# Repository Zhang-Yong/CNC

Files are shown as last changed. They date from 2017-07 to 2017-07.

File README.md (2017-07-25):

# CNC
  My CNC project in 2013, this project makes myself familiar with mechnical design and installation. All the parts are built and assemblied in Solidworks before order on the net. I bought a bench drill to assemble every raw material. Below are drawings before and after build. After build it up, the CNC can move according to input x, y, Z axis.

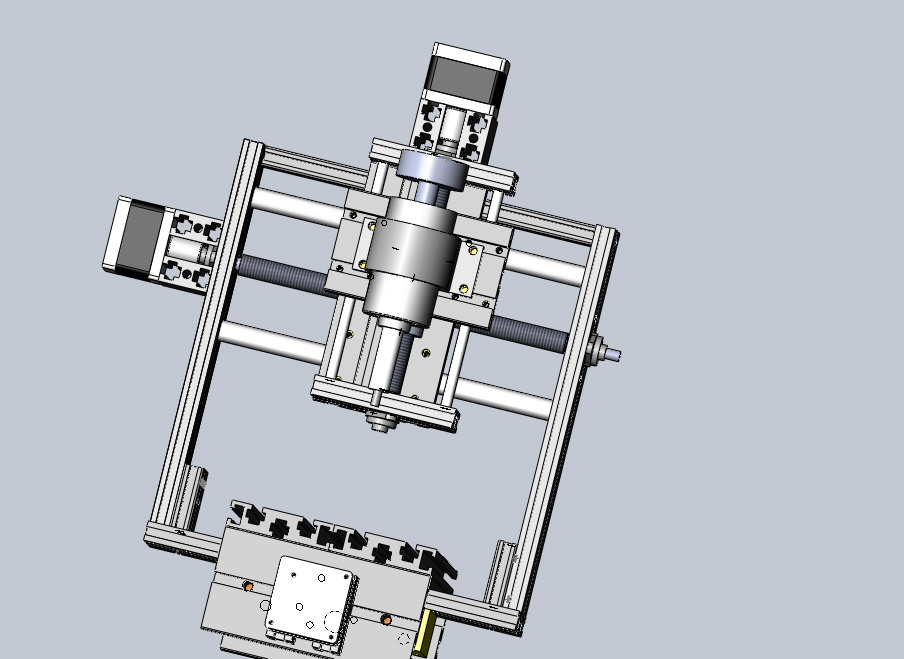
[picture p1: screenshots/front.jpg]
Front view


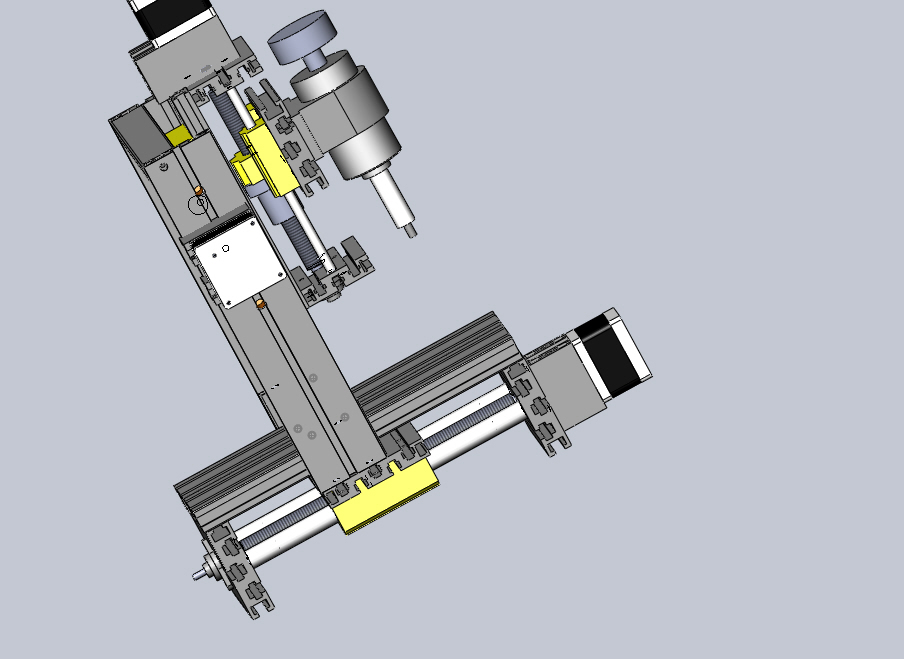
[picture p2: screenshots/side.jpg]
side view


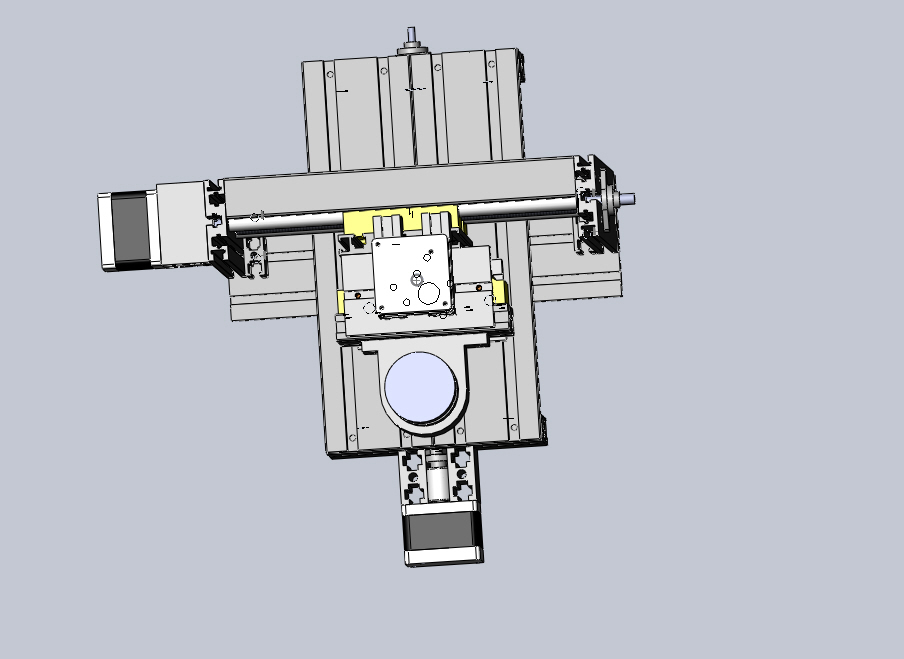
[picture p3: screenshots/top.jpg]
top view


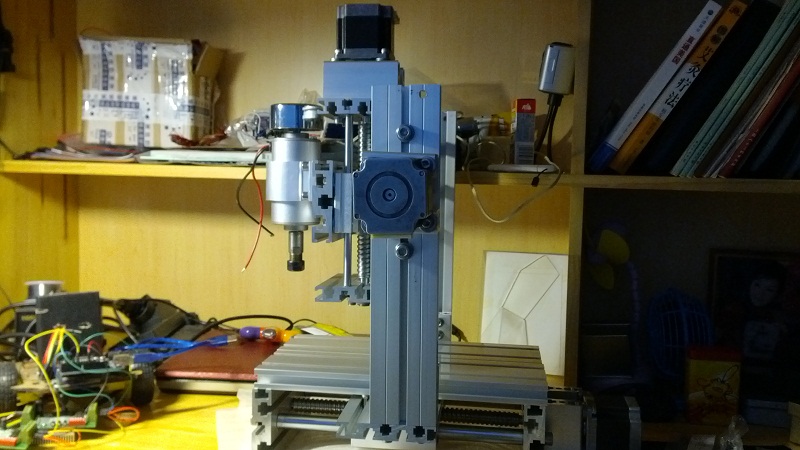
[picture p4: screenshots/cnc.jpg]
Real picture


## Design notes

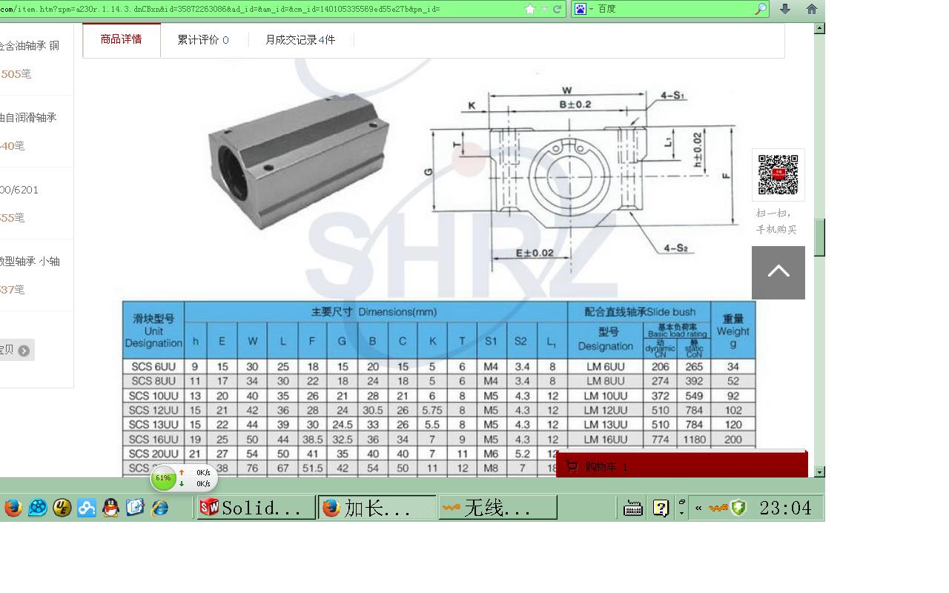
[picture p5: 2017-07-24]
my_CNC_Solidworks_File/┴у╝■═╝╞м/scs8LUU.JPG

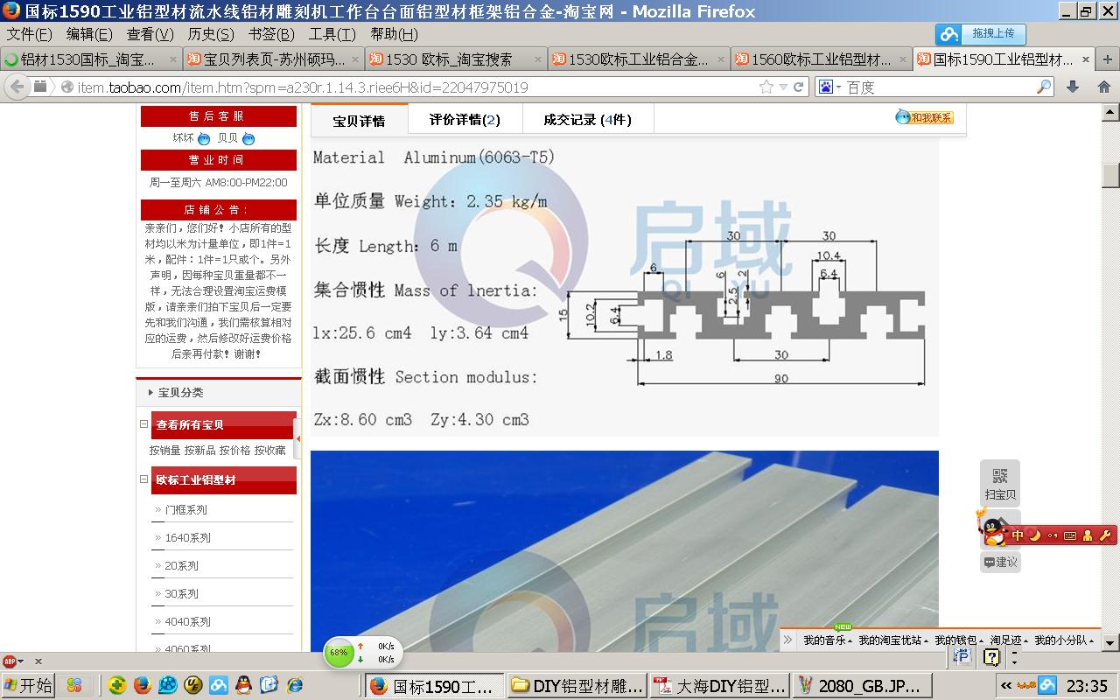
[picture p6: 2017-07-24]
my_CNC_Solidworks_File/┴у╝■═╝╞м/1590_GB.JPG

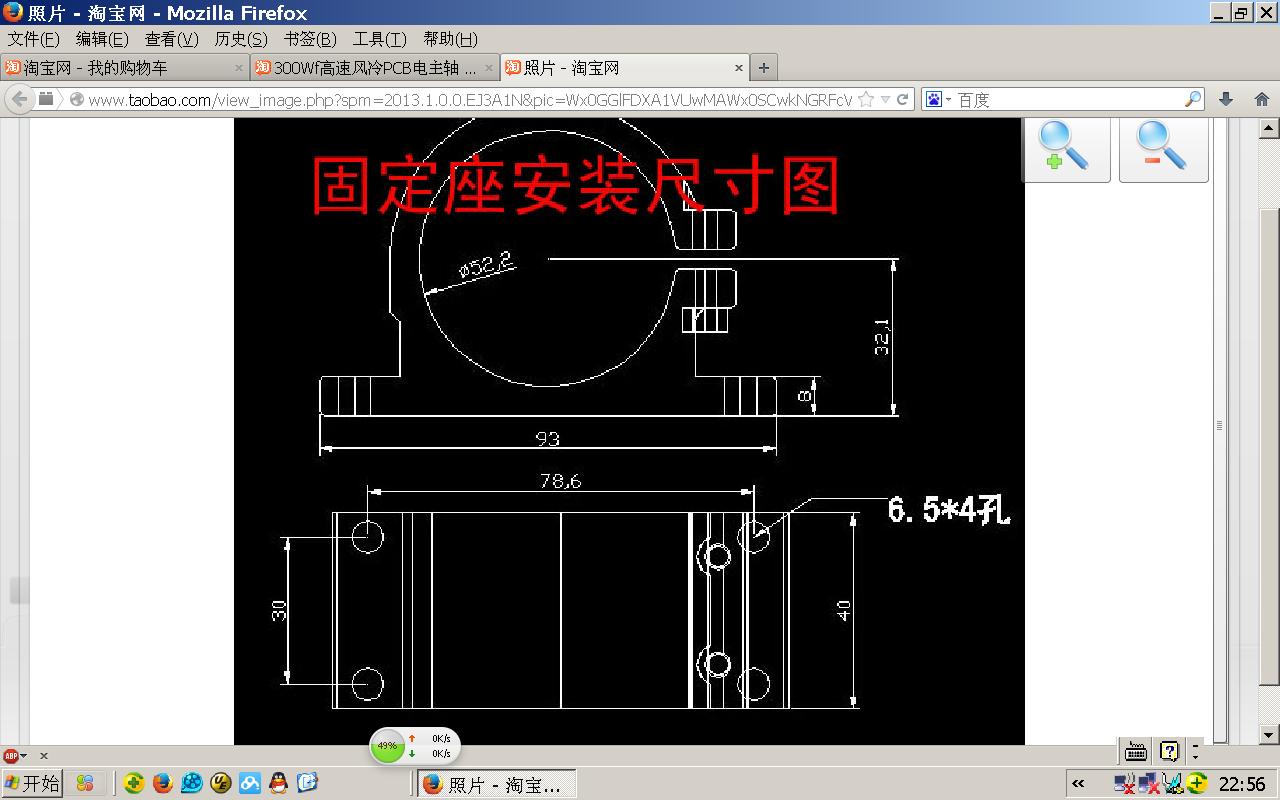
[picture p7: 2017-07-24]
my_CNC_Solidworks_File/┴у╝■═╝╞м/╓ў╓с╣╠╢и╫∙.JPG

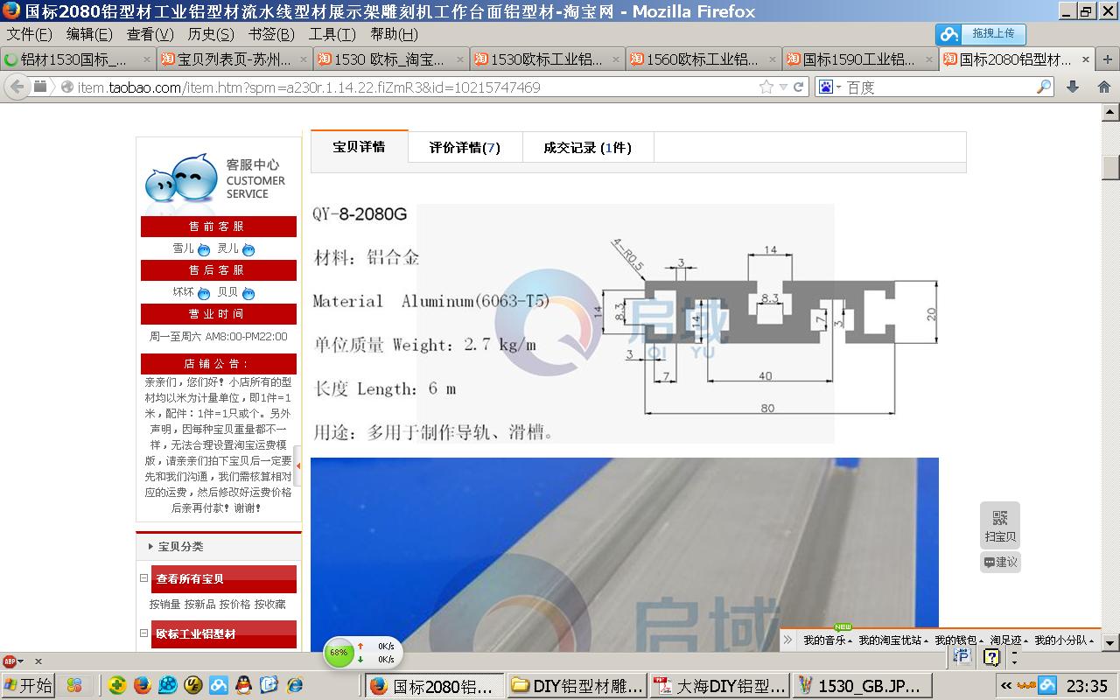
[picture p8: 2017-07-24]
my_CNC_Solidworks_File/┴у╝■═╝╞м/2080_GB.JPG

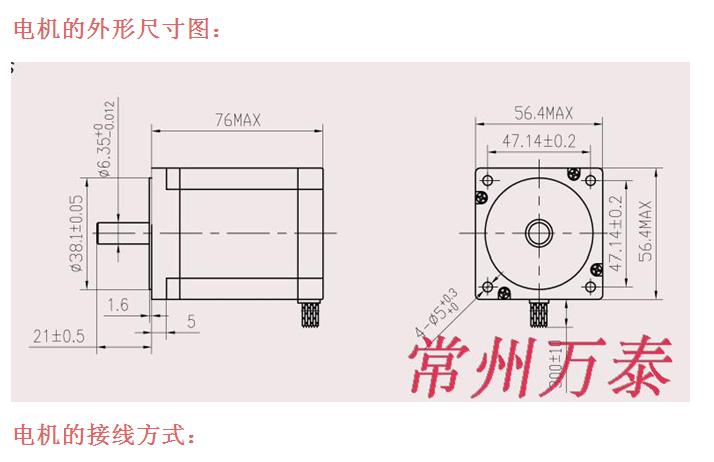
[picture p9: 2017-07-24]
my_CNC_Solidworks_File/┴у╝■═╝╞м/57▓╝╜°.jpg

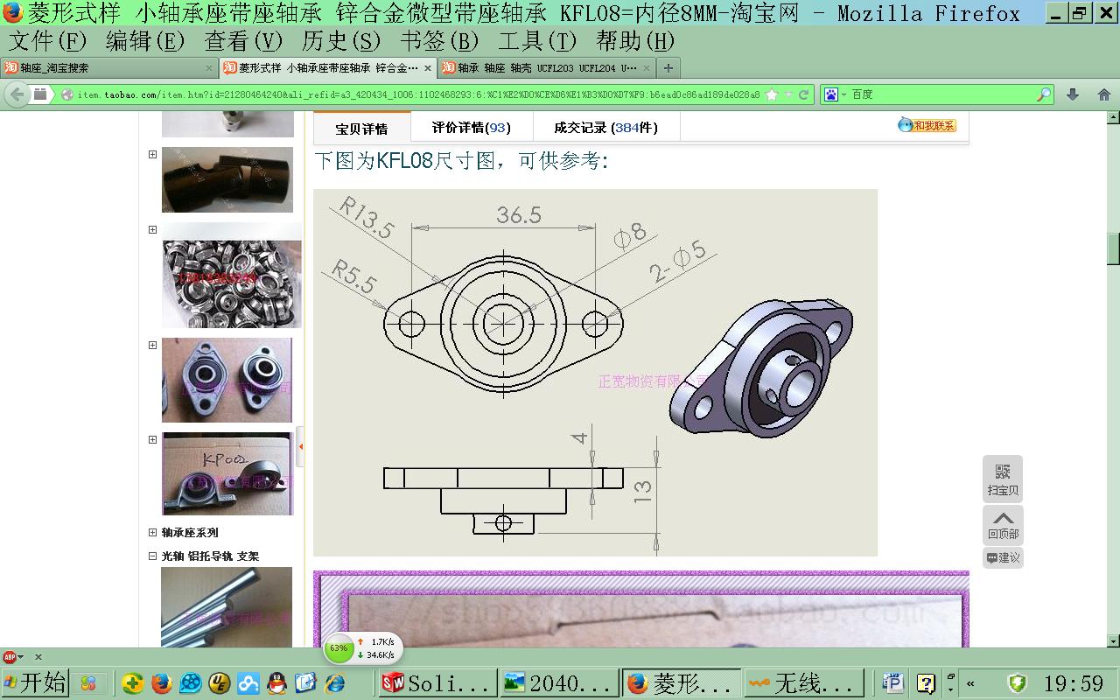
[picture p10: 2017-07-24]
my_CNC_Solidworks_File/┴у╝■═╝╞м/KFL08_╓с╫∙.JPG

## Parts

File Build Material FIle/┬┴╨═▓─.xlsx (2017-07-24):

 | 型号 | 标准 | 长度 | 数量 | 用途
铝型材 | 2080 | 国标 | 290 mm | 2 | 台面板
铝型材 | 2080 | 国标 | 160 mm | 2 | Y 轴前后板
铝型材 | 2080 | 国标 | 128 mm | 1 | Z 轴移动板
铝型材 | 1590 | 国标 | 290 mm | 1 | Y 轴移动板
铝型材 | 1590 | 国标 | 200 mm | 1 | X 轴移动板
铝型材 | 1560 | 国标 | 300 mm | 2 | X 轴左右板
铝型材 | 1560 | 国标 | 110 mm | 2 | Z 轴上下板
铝型材 | 2040A | 国标 | 75 mm | 2 | Z 轴电机固定板
铝型材 | 2040A | 国标 | 60 mm | 4 | XY 轴电机固定板
铝型材 | 1530 | 国标 | 260 mm | 1 | X 轴上连接板
铝型材 | 1530 | 国标 | 50 mm | 4 | XY 轴连接板
切割要求：
雕刻机用铝型材， 切割要精确， 断面要平整，没有毛刺。

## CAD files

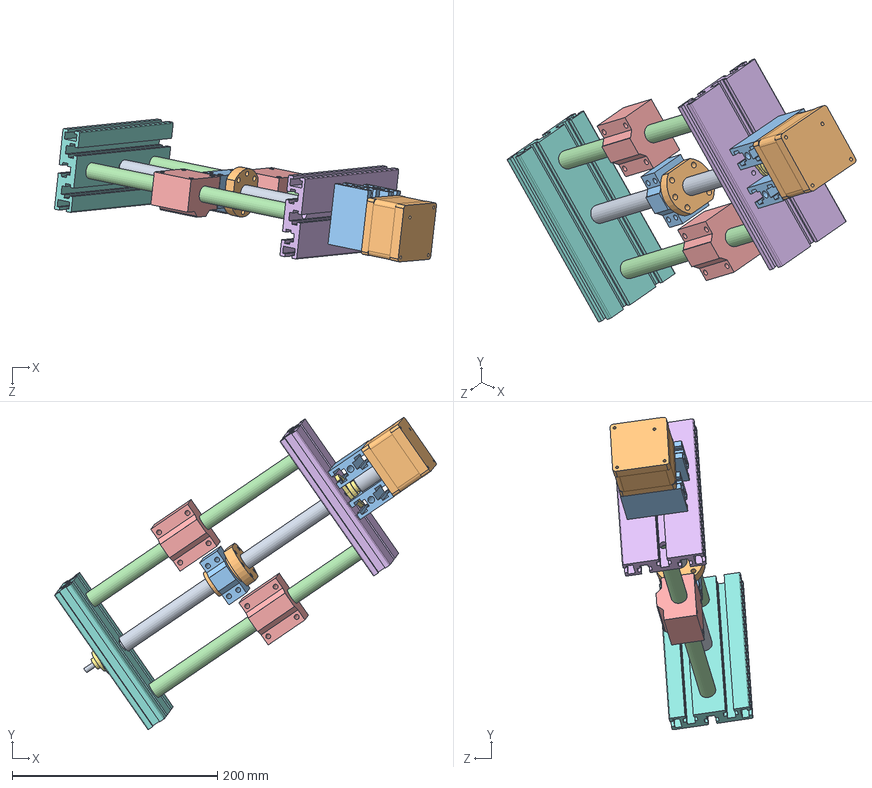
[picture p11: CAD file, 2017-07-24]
my_CNC_Solidworks_File/╫░┼ф╠х/╣Ў╓щ╦┐╕╦_Y.SLDASM
372.6 x 304.8 x 139.3 mm
滚珠丝杆_Y轴_T1605_new
滚珠丝杆1605螺母
SCS16UU_Half
光轴16x250mm_Y轴_new x 2
SCS16UU x 2
2080_160_Y_Back_电机
KFL08_轴座 x 2
2080_160_Y_Front_手轮
联轴器6_35x6_35
57步进电机轴
2040_GB_XY_60 x 2

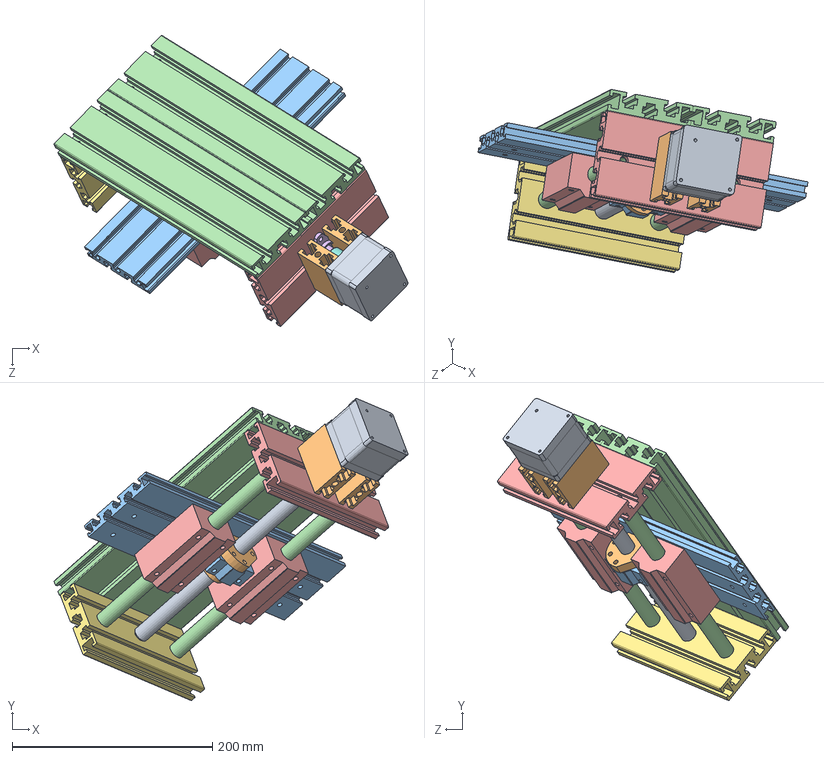
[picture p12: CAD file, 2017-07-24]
my_CNC_Solidworks_File/╫░┼ф╠х/Y_╓с_╠и├ц.SLDASM
353.5 x 301.8 x 291.0 mm
滚珠丝杆_Y轴_T1605_new
滚珠丝杆1605螺母
SCS16UU_Half
光轴16x250mm_Y轴_new x 2
2080_160_Y_Back_电机
KFL08_轴座 x 2
2080_160_Y_Front_手轮
联轴器6_35x6_35
57步进电机轴
2040_GB_XY_60 x 2
1590_290_Y
2080_Table_290_new x 2
SCS16LUU x 2

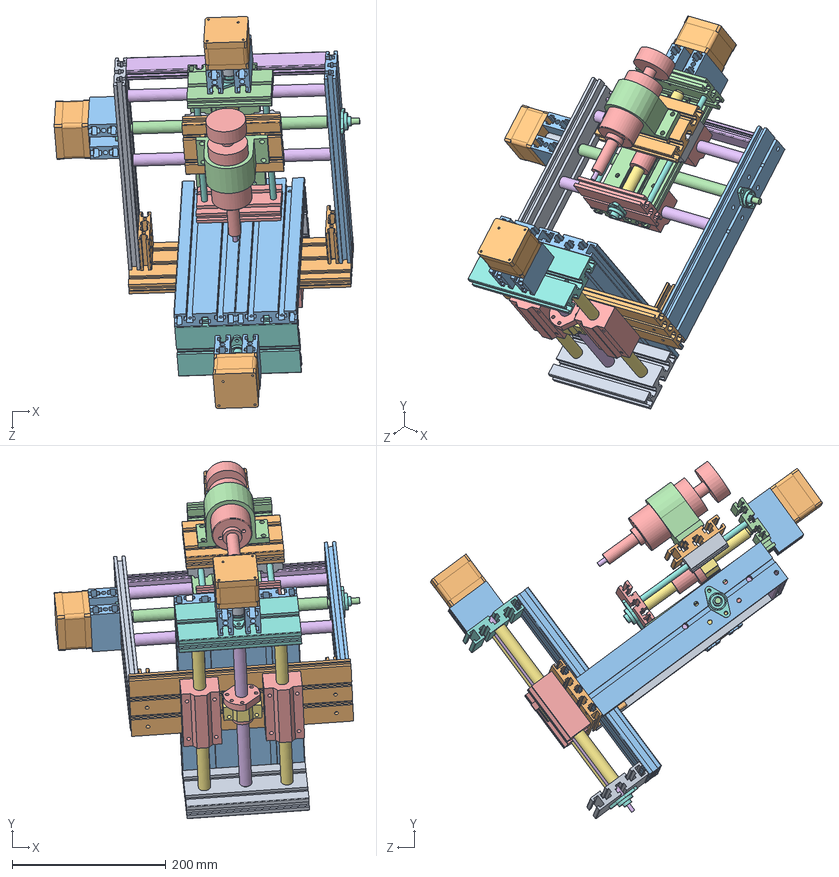
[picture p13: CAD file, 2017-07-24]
my_CNC_Solidworks_File/╫░┼ф╠х/╫▄╫░.SLDASM
398.0 x 465.4 x 510.4 mm
1560_300_X x 2
1530_50_XY x 4
1560_300_X_Right
滚珠丝杆_X轴_T1605
滚珠丝杆1605螺母 x 3
光轴16x250mm_X轴 x 2
SCS16UU_Half x 3
KFL08_轴座 x 6
联轴器6_35x6_35 x 3
57步进电机轴 x 3
2040_GB_XY_60 x 4
1590_200_X
SCS16LUU x 4
1530_260_X
滚珠丝杆_Z轴_T1605
光轴8x170mm_Z轴 x 2
SCS8LUU x 2
2080_128_Z
2040_GB_Z_75 x 2
1560_110_Z
1560_110_Z_下板
滚珠丝杆_Y轴_T1605_new
光轴16x250mm_Y轴_new x 2
2080_160_Y_Back_电机
2080_160_Y_Front_手轮
1590_290_Y
2080_Table_290_new x 2
主轴电机座
主轴电机
雕刻刀

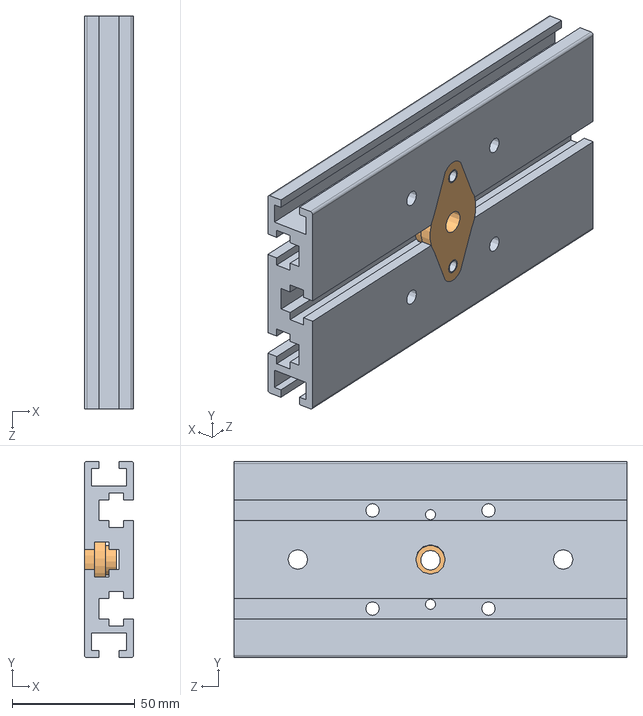
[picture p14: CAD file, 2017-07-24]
my_CNC_Solidworks_File/╫░┼ф╠х/╫░┼ф╠х2.SLDASM
20.0 x 80.0 x 160.0 mm
2080_160_Y_Back_电机
KFL08_轴座

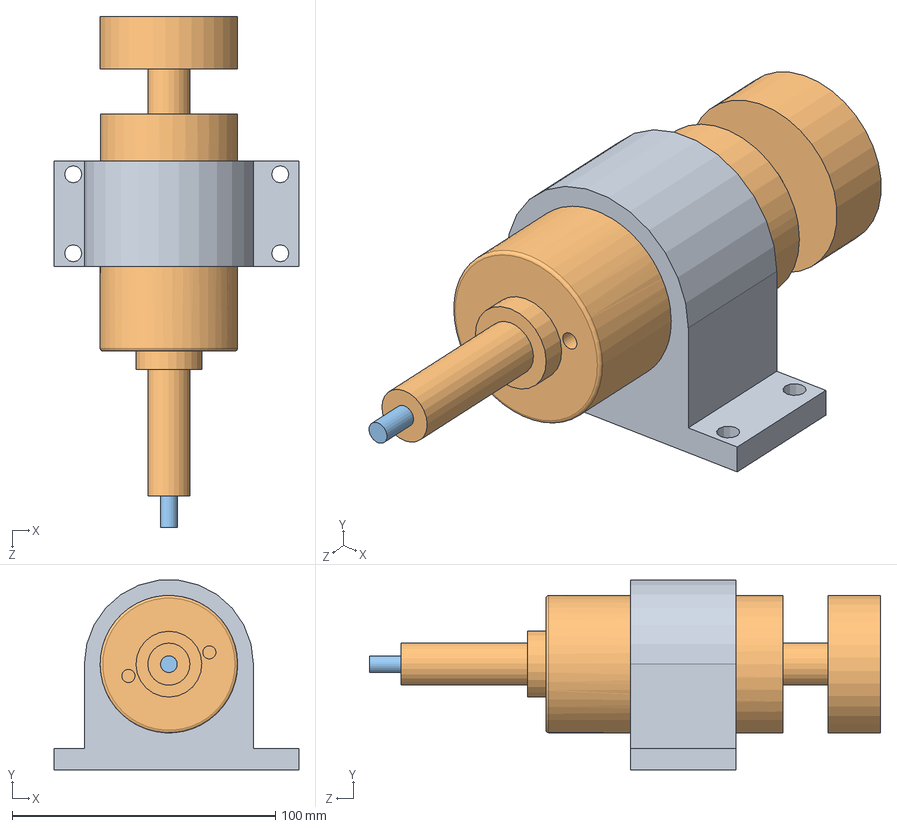
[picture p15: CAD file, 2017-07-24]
my_CNC_Solidworks_File/╫░┼ф╠х/╓ў╓с.SLDASM
93.0 x 72.0 x 194.0 mm
主轴电机座
主轴电机
雕刻刀

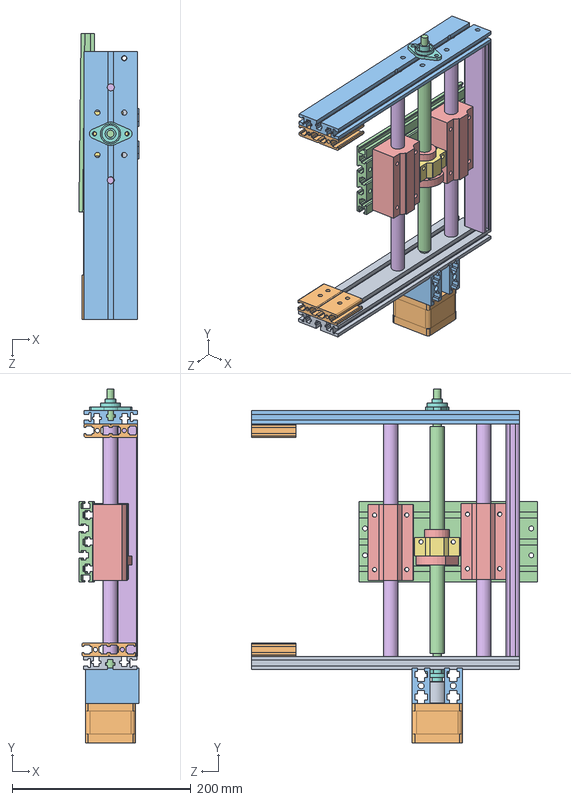
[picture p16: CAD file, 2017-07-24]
my_CNC_Solidworks_File/╫░┼ф╠х/X_╓с.SLDASM
67.4 x 396.0 x 320.4 mm
1560_300_X x 2
1530_50_XY x 4
1560_300_X_Right
滚珠丝杆_X轴_T1605
滚珠丝杆1605螺母
光轴16x250mm_X轴 x 2
SCS16UU_Half
KFL08_轴座 x 2
联轴器6_35x6_35
57步进电机轴
2040_GB_XY_60 x 2
1590_200_X
SCS16LUU x 2
1530_260_X

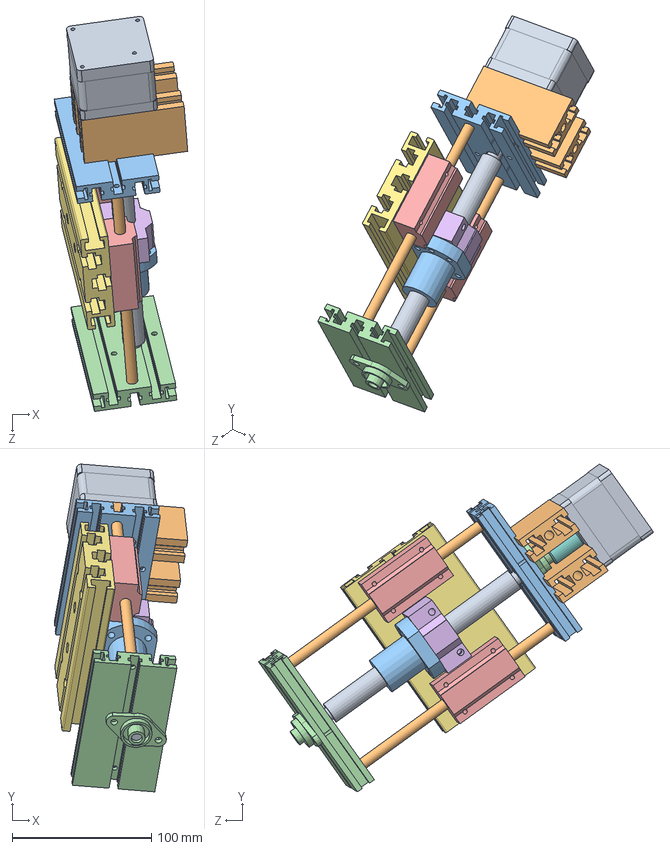
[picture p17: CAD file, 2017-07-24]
my_CNC_Solidworks_File/╫░┼ф╠х/Z╓с.SLDASM
96.1 x 235.8 x 284.1 mm
滚珠丝杆_Z轴_T1605
光轴8x170mm_Z轴 x 2
滚珠丝杆1605螺母
KFL08_轴座 x 2
SCS8LUU x 2
SCS16UU_Half
2080_128_Z
联轴器6_35x6_35
57步进电机轴
2040_GB_Z_75 x 2
1560_110_Z
1560_110_Z_下板

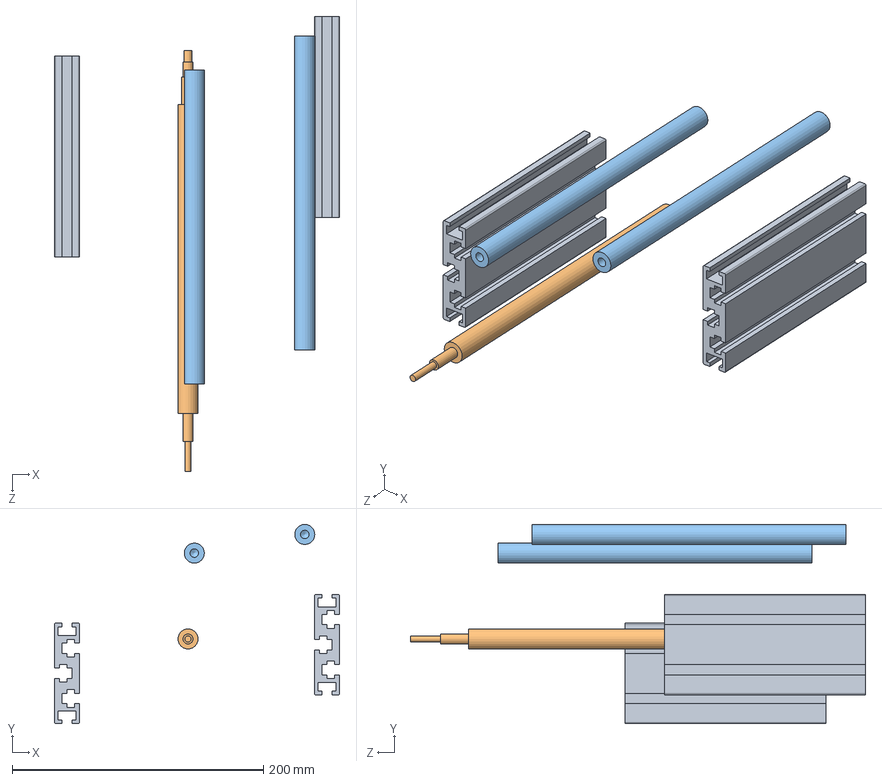
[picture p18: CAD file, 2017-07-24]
my_CNC_Solidworks_File/Y╓с.SLDASM
227.0 x 158.6 x 362.2 mm
2080_160_Y_Back_Front x 2
滚珠丝杆_Y轴_T1605_new
光轴16x250mm_Y轴_new x 2

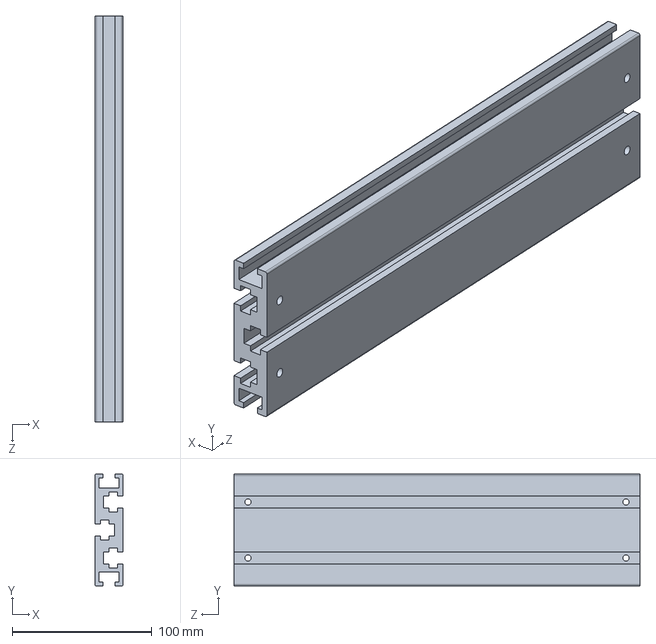
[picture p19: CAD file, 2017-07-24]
my_CNC_Solidworks_File/2080_Table_290_new.SLDPRT
20.0 x 80.0 x 290.0 mm

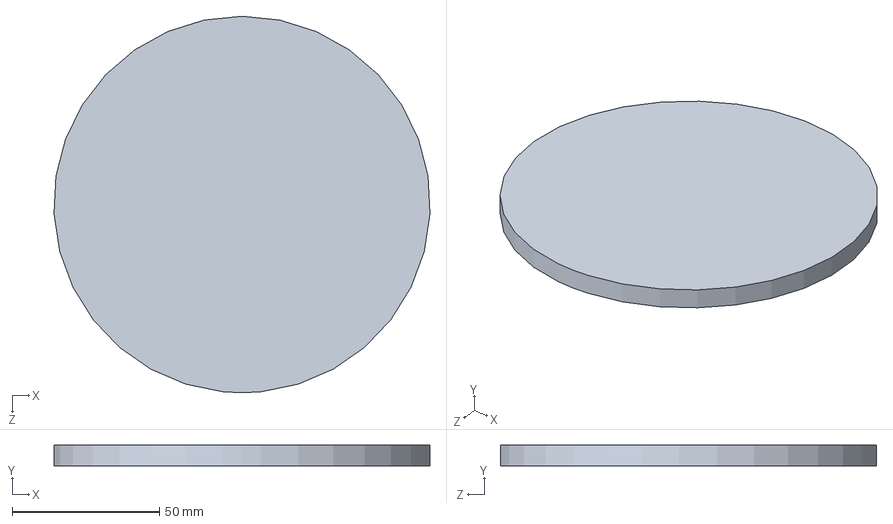
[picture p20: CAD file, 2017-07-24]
my_CNC_Solidworks_File/┴у╝■═╝╞м/┴у╝■1.SLDPRT
127.8 x 7.00 x 128.0 mm

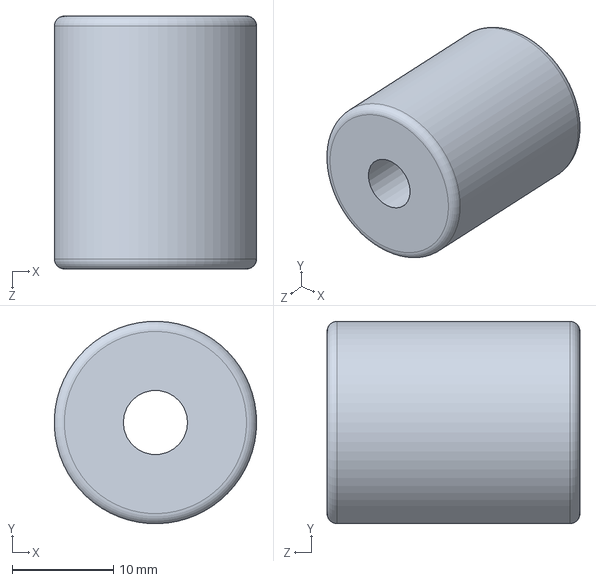
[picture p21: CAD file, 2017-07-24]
my_CNC_Solidworks_File/┴к╓с╞ў6.35mm.SLDPRT
20.0 x 20.0 x 25.0 mm

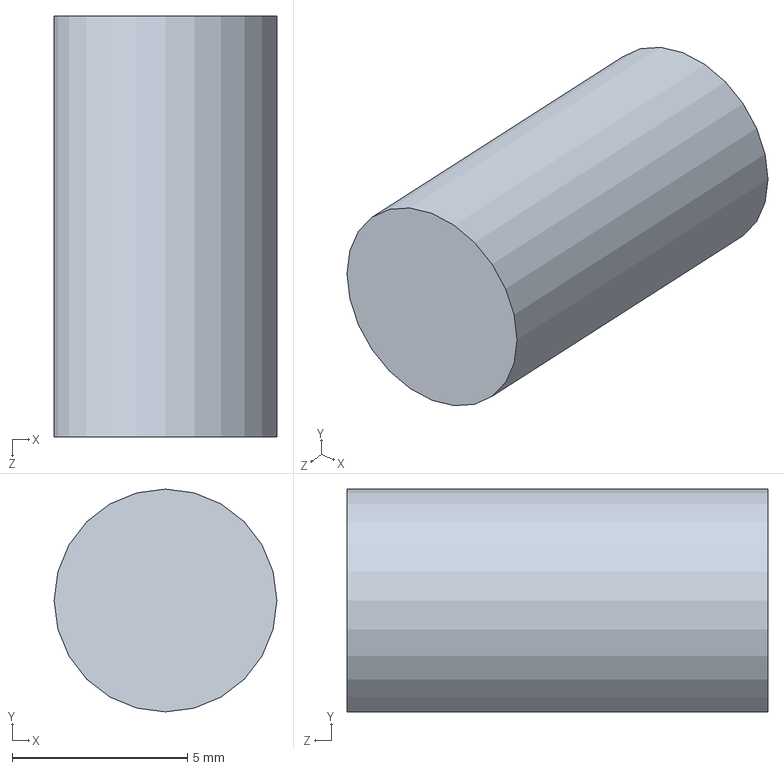
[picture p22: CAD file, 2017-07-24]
my_CNC_Solidworks_File/╡ё┐╠╡╢.SLDPRT
6.35 x 6.35 x 12.0 mm

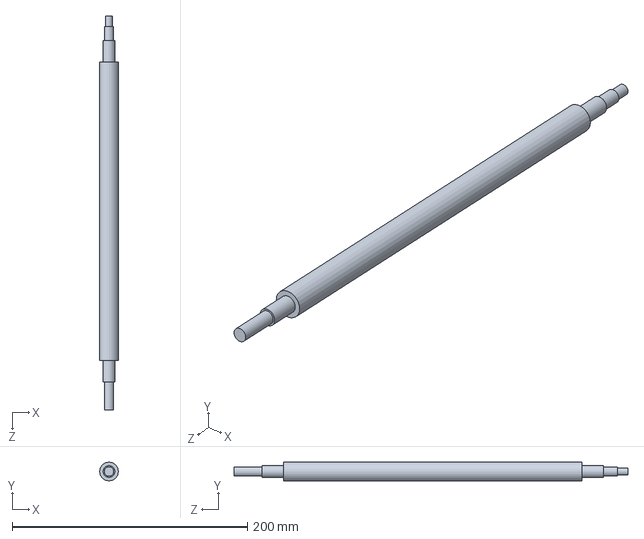
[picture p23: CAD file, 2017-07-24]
my_CNC_Solidworks_File/╣Ў╓щ╦┐╕╦_X╓с_T1605.SLDPRT
16.0 x 16.0 x 335.0 mm

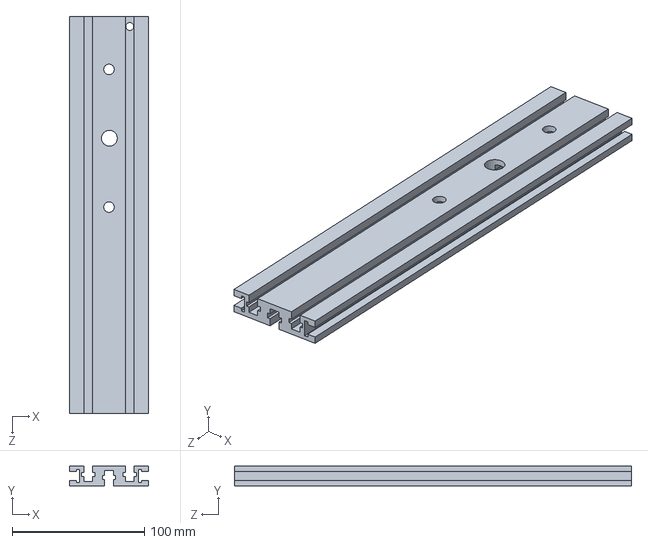
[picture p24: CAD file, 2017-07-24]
my_CNC_Solidworks_File/1560_300_X.SLDPRT
60.0 x 15.0 x 300.0 mm

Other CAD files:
my_CNC_Solidworks_File/╫░┼ф╠х/╫▄╫░_side.SLDASM
my_CNC_Solidworks_File/┴к╓с╞ў6_35x6_35.SLDPRT
my_CNC_Solidworks_File/2040_GB_Z_75.SLDPRT
my_CNC_Solidworks_File/SCS16LUU.SLDPRT
my_CNC_Solidworks_File/1530_260_X .SLDPRT
my_CNC_Solidworks_File/1530_50_XY .SLDPRT
my_CNC_Solidworks_File/1560.SLDPRT
my_CNC_Solidworks_File/1560_110_Z.SLDPRT
my_CNC_Solidworks_File/1560_110_Z_╧┬░х.SLDPRT
my_CNC_Solidworks_File/1560_300_X_Right.SLDPRT
my_CNC_Solidworks_File/1590_200_X.SLDPRT
my_CNC_Solidworks_File/1590_290_Y.SLDPRT
my_CNC_Solidworks_File/2040_GB_XY_60.SLDPRT
my_CNC_Solidworks_File/2080_128_Z.SLDPRT
my_CNC_Solidworks_File/2080_160_Y_Back_╡ч╗·.SLDPRT
my_CNC_Solidworks_File/2080_160_Y_Front_╩╓┬╓.SLDPRT
my_CNC_Solidworks_File/57▓╜╜°╡ч╗·╓с.SLDPRT
my_CNC_Solidworks_File/KFL08_╓с╫∙.SLDPRT
my_CNC_Solidworks_File/SCS16UU.SLDPRT
my_CNC_Solidworks_File/SCS16UU_Half.SLDPRT
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

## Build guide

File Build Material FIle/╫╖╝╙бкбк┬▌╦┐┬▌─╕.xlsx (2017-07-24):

清单 | 数量
FX10M5 | 50
FX14M4 | 15
FX14M5 | 30
FX14M8 | 10
尼龙垫脚 M8*50*50D | 6
2080GW,160mm | 1
1530国标， 260mm | 1 | 上次忘发

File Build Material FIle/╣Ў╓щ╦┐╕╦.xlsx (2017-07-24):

清单：
滚珠丝杆 3根,台湾原装TBI螺母 | 光轴三根 | SCS16LUU，4个 | SCS8LUU, 2个 | SCS16UU壳，2个 | 每个壳中间一切二，图在下面
6.35*6.35联轴器3个， KFL08 6个
滚珠丝杆
 |  |  |  |  |  | 3根丝杆两端磨缺口， 固定联轴器和手轮
光轴：
轴两端按图加工
SCS16 UU 加工图， 一个切成2块， 并且打孔如下图
